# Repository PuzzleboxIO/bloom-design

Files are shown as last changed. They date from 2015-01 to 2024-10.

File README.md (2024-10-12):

bloom-design
============

Puzzlebox Bloom - 3D Design

by Puzzlebox Productions, LLC
http://puzzlebox.io/bloom

puzzlebox_bloom_openscad

Watch the video (https://www.youtube.com/watch?v=KhwO3Cl5jvA)

Assembly Guide:
https://puzzlebox.io/bloom-assembly/

License: Creative Commons - Attribution - Share Alike
https://creativecommons.org/licenses/by-sa/3.0

source credit: "Blossoming Lamp" by Emmett Lalish [https://www.thingiverse.com/thing:37926]
source credit: "Arduino OpenSCAD mounting library (v2.0)" by Kelly Egan [https://github.com/kellyegan/OpenSCAD-Arduino-Mounting-Library]
source credit: "Pin Connectors V3" by Tony Buser and Emmett Lalish [http://www.thingiverse.com/thing:33790]
source credit: "Write.scad" by Harlan Martin [http://www.thingiverse.com/thing:16193]

creative credit: Patrick Jouin [http://www.mgxbymaterialise.com/limited-editions/mgxmodel/detail/detail/71]

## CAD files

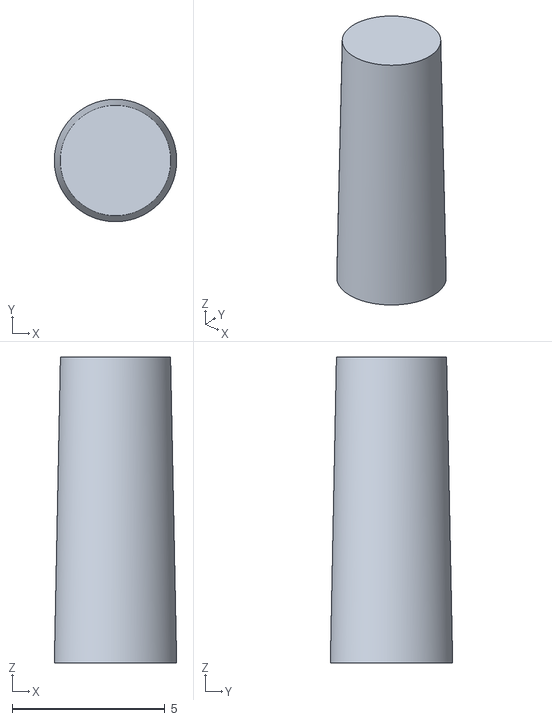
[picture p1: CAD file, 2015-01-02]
render/Peg.stl
4.00 x 4.00 x 10.0

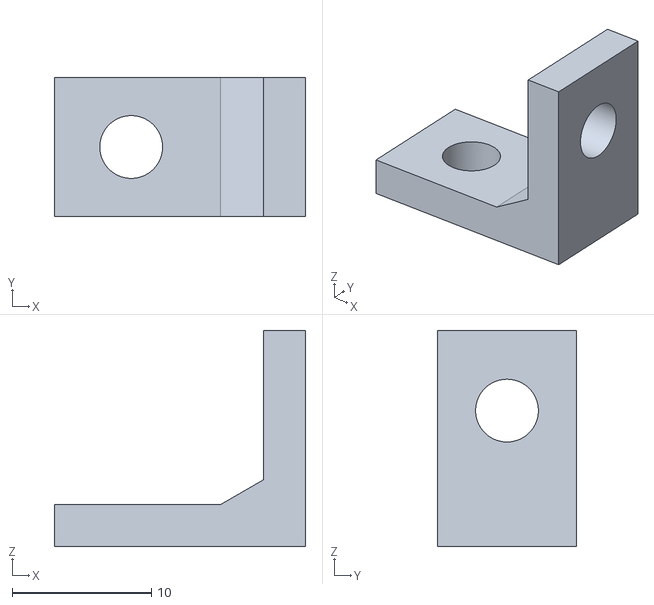
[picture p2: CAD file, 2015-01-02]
render/Clip.stl
18.0 x 10.0 x 15.5

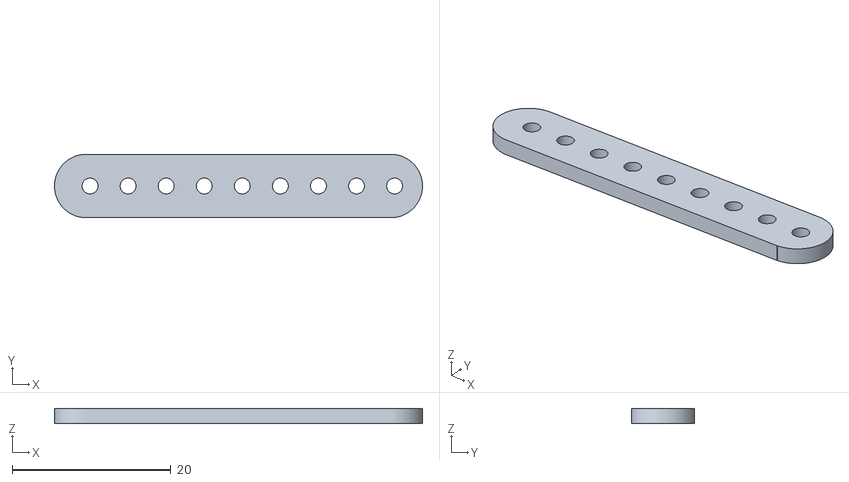
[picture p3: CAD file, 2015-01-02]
render/Rod.stl
46.4 x 8.00 x 1.92

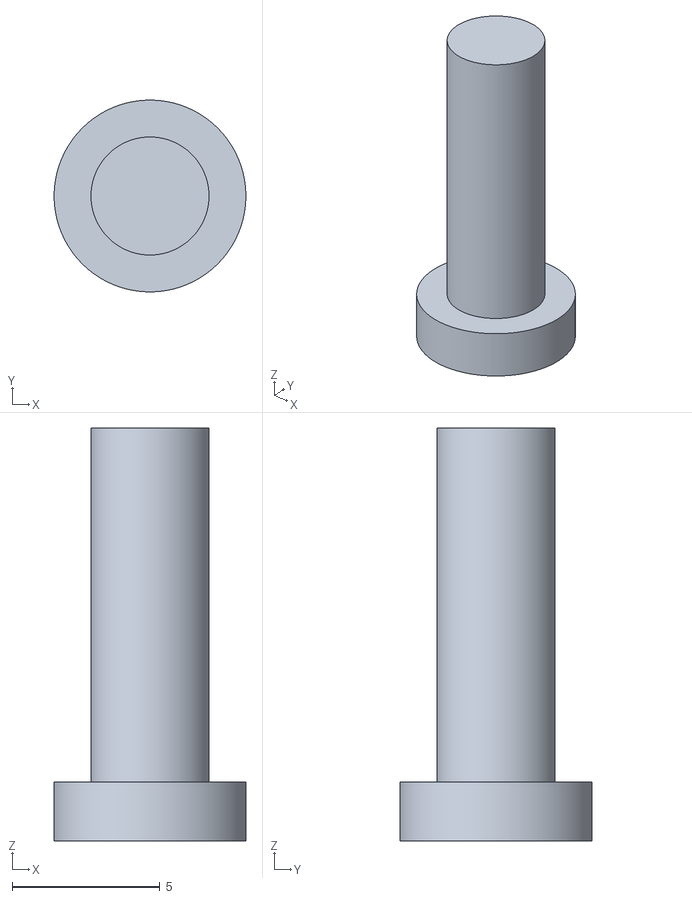
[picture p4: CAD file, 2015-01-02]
render/Cover.stl
6.50 x 6.50 x 14.0

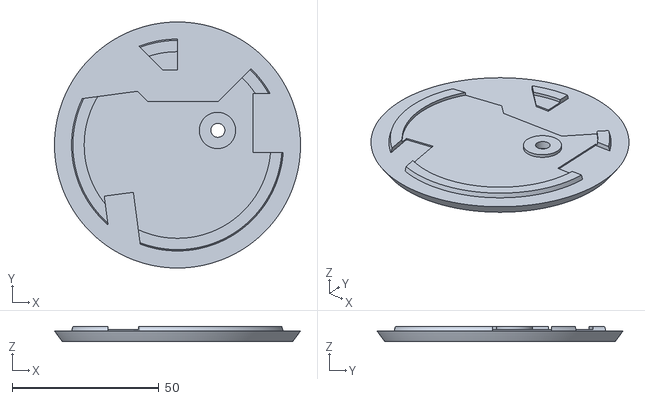
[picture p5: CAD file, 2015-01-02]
render/Bottom.stl
83.8 x 83.8 x 5.09

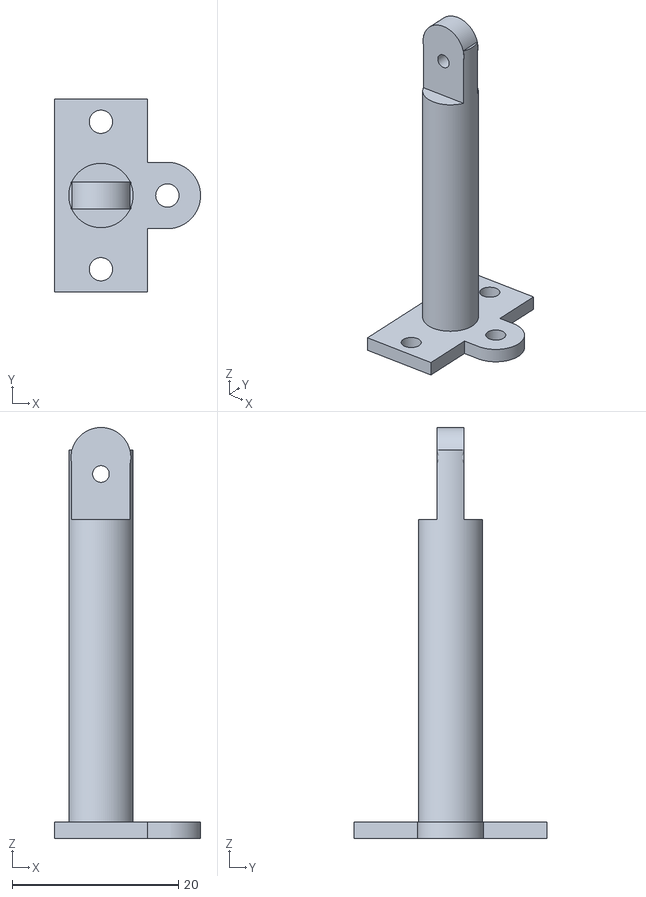
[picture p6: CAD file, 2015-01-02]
render/Piston.stl
17.6 x 23.2 x 49.5

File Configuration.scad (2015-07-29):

// Puzzlebox Bloom
//
// component: Configuration
//
// by Puzzlebox Productions, LLC
// http://puzzlebox.io/bloom
//
// License: Creative Commons - Attribution - Share Alike
//          https://creativecommons.org/licenses/by-sa/3.0
//
// source credit: "Blossoming Lamp" by Emmett Lalish [https://www.thingiverse.com/thing:37926]
// creative credit: Patrick Jouin [http://www.mgxbymaterialise.com/limited-editions/mgxmodel/detail/detail/71]
//
// source credit: "Arduino OpenSCAD mounting library (v2.0)" by Kelly Egan [https://github.com/kellyegan/OpenSCAD-Arduino-Mounting-Library]
// source credit: "Pin Connectors V3" by Tony Buser and Emmett Lalish [http://www.thingiverse.com/thing:33790]
// source credit: "Write.scad" by Harlan Martin [http://www.thingiverse.com/thing:16193]


// Design
// Note: All measurements are in mm


print_scale = 0.8; // divide by this number pricely-measured 
                   // facets which cannot be scaled down
                   // for example, screw holes, LEDs, docks, etc.


// Tolerances
tol=0.45 / print_scale; // tolerance for sliding [Printrbot Simple Metal (2014, 2015)]
// tol=0.4 / print_scale; // tolerance for sliding [MakerBot Replicator 2]
// tol=0.3 / print_scale; // tolerance for sliding [Ultimaker 2]
// tol=0.4 / print_scale; // tolerance for sliding [daVinci 1.0]


// Bulb Platform
bulb_platform_position = -51; // flush with top of socket (w/ heigth 6)
bulb_platform_diameter = 34;
bulb_platform_height = 4; // (thickness)
// bulb_platform_height = 7; // (thickness)


// Bulb Pivot
// pivot_outer_diameter = 12.5 + 0.5;
pivot_outer_diameter = 12.5 + 0.5 + 1;
pivot_inner_diameter = 4;

// pivot_thickness = 4 + 0.5;
// pivot_thickness = 4 + 0.5 + 1;
pivot_thickness = 4 + 0.5 + 2;

// pivot_reinforcements_thickness = pivot_thickness-1;
pivot_reinforcements_thickness = 3.5;

pivot_extension = 2.5 + 2 + 5;
// pivot_position_z = bulb_platform_position - bulb_platform_height /2 - pivot_extension - 1.825; // dropped by 2.5mm in order to compensate for the head of the pivot arm
// pivot_position_z = bulb_platform_position - bulb_platform_height /2 - pivot_extension - 2.825 + 0.132;
pivot_position_z = bulb_platform_position - bulb_platform_height /2 - pivot_extension - 2.825 + 0.132 + 0.25;
// pivot_hole_position_z = pivot_position_z-pivot_extension/2 + 2.5 + 2;
pivot_hole_position_z = pivot_position_z-pivot_extension/2 + 2.5;
reinforcement_height = 13;
pivot_round_screw_hole = false;
pivot_square_bolt_hole = true;
// pivot_bolt_screw_hole_diameter = pivot_thickness-1;
pivot_bolt_screw_hole_diameter = 3.5;
// bulb_pivot_offset_x_purple = 10;
bulb_pivot_offset_x_purple = 10+1+0.1;
// bulb_pivot_offset_x_violet = -10;
bulb_pivot_offset_x_violet = -10-1-0.1;


// Branch
slice_mount_plate = false; // Crop a vertical stripe out of the mount plate


// Blossom
height_of_lamp = 76.1;
lamp_error_at_z = height_of_lamp - 31;
height_of_lamp_crop = height_of_lamp - lamp_error_at_z + 10; // crop before z error in model
lamp_crop_pos_z = lamp_error_at_z + (height_of_lamp_crop/2); // "

height_of_lamp_crop = height_of_lamp + 119.75; // crop entire bulb
lamp_crop_pos_z = 50; // "


// Petals
petal_stand_height = 3;


// Cage screw holes
cage_screw_diameter = 4 / print_scale;
// cage_screw_height = 15;
// cage_screw_height = 15 + 100;
// cage_screw_height = 15 + 35; // should be enough to reach through to outer edge of stand but not intersect with support ring in base socket
cage_screw_height = 15 -1 ; // leave a 1-2mm wall between edge of cage()

cage_screw_tilt_degrees = 12;


// Light holes
light_hole_diameter = 24; // easy_mount_cropping
// light_hole_diameter = 15; // small diameter
// light_hole_diameter = 12.5 / print_scale; // if you try to scale this it will create a gap between the purple pivots underneath

// led_diameter = 6 / print_scale; // exact measure is closer to 5.5mm but the heat seems to shring the final size of the hole
led_diameter = (light_hole_diameter * print_scale) / print_scale; // grow large to let more light through


// Bulb Socket
// bulb_socket_crop_position_height = 47; // top of male arm joints
bulb_socket_crop_position_height = 38;
bulb_socket_split_x = 100;
bulb_socket_split_y = 100;
bulb_socket_split_z = 172;
bulb_socket_alternate_joints_position = false; // original lamp alternates

bulb_socket_height = 20; // (calculated)

socket_outer_diameter = 75.75; // (calculated)
socket_rim = socket_outer_diameter - 15.2; // (calculated)


// Base Stand
stand_crop_microusb_slot = true;
stand_crop_dc_adapter_slot = true;

stand_render_microcontroller_mount = true;

stand_crop_microcontroller_mount = true;
// stand_crop_microcontroller_mount = false;

stand_render_lid_mount = true;

build_base_socket = true;
// build_base_socket = false;

// build_inner_support_walls = true;
build_inner_support_walls = false;

// linear_tapered_cylinder = true;
linear_tapered_cylinder = false; // original base socket

// slice_socket_center_from_bottom = true;
slice_socket_center_from_bottom = false;

// enable_render_side_petals = true;
// enable_render_side_petals = false;
enable_render_side_petals_left = false;
enable_render_side_petals_right = false;
// enable_render_side_petals_right = true;

// enable_front_wall_hole = true;
enable_front_wall_hole = false;

// front_wall_hole_tapered = false;
front_wall_hole_tapered = true;

// reinforce_front_wall_hole = true;
reinforce_front_wall_hole = false;

stand_extrude_walls = true;

stand_crop_position_x = 87.5;
stand_crop_position_height = 70;
stand_crop_x = 100;
stand_crop_y = 100;
stand_crop_z = 172;

// rotate_screw_holes = [0,0,0]; // 2 holes on forward half, to either side
rotate_screw_holes = [0,0,180]; // 1 hole on forward half, centered
rotate_socket_screw_holes_offset = [0,0,0];

// slice_socket_up_from_bottom = 22.5;
slice_socket_up_from_bottom = 22.5-10;

stand_test_brim_diameter = 135.925;
stand_test_brim_height = 5;

// stand_height = 42.5; // (calculated)
stand_height = 43; // (calculated)
base_extrude_walls_scale_height = 44;

// stand_total_height = stand_height+bulb_socket_height;
stand_total_height = stand_height+bulb_socket_height*2;

stand_cylinder_diameter = 97.5; // (calculated)
stand_cylinder_width = 8.75; // (calculated)
// stand_cylinder_width = 8.5175; // "
// stand_cylinder_width = 8.515; // "
// stand_cylinder_width = 8.5; // "

// base_cylinder_side_hole = 50;
base_cylinder_side_hole = 60;

stand_extrude_walls_scale = (stand_cylinder_diameter - stand_cylinder_width) / stand_cylinder_diameter;

stand_petal_crop_scale_large = 1.2;
stand_petal_crop_scale_medium = 0.8;
stand_petal_crop_scale_small = 0.6;
stand_petal_crop_scale_rear = 1;
// stand_petal_crop_scale_rear = 0.95;
// stand_petal_crop_scale_rear_petal = 0.6;
stand_petal_crop_scale_rear_petal = 0.6;

base_servo_mount_offset_x = -5-5-5;
// base_servo_mount_offset_y = 7.5;
// base_servo_mount_offset_y = -8;
// base_servo_mount_offset_y = 7.5-8;
// base_servo_mount_offset_y = 1.5;
base_servo_mount_offset_y = 1.5-2.5; // controls how far back the servo sits under the piston and connecting rod
base_servo_mount_offset_z = 31.5*2;

// base_servo_mount_crop_from_back = 3.5; // widened for TowerPro MG995
base_servo_mount_crop_from_back = 2.5;

// base_servo_mount_screws_offset_z = -0.75;
base_servo_mount_screws_offset_z = -1;

stand_socket_height = 25; // (calculated)
// stand_socket_crop_top = 3;
stand_socket_crop_top = 4; // (measured)

// actual_stand_height = stand_height+bulb_socket_height+mount_plate_thickness/4+16.7;
// actual_stand_height = 81.325;
actual_stand_height = 83;
stand_extension = 22;
adjusted_stand_height = actual_stand_height + stand_extension;

servo_cylinder_height = 53;

stand_wall_width = 3.5;

servo_cube_x=50;
servo_cube_y=80;
servo_cube_z=servo_cylinder_height;

extrude_base_scale_x = 0.95;
extrude_base_scale_y = 0.95;
extrude_base_scale_z = 0.86359;
extrude_base_t = -5;

stand_servo_x_offset = 0;
stand_servo_y_offset = -34+10;
stand_servo_z_offset = 30;

// microcontroller_height = 15 / print_scale;
// microcontroller_length = 76 / print_scale;
// microcontroller_width = 54 / print_scale;

// microcontroller_height = 15;
microcontroller_height = 13;
microcontroller_length = 76;
// microcontroller_width = 54;
microcontroller_width = 58;

// microcontroller_x_offset = 18;
microcontroller_x_offset = 18-7;
microcontroller_y_offset = 12;
microcontroller_offset_from_bottom = 12;

// microcontroller_bolt_width = 0;
microcontroller_bolt_width = 2.5;
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

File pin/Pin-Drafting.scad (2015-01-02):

// Puzzlebox Bloom
//
// component: Pin
//
// edition: Drafting
//
// by Puzzlebox Productions, LLC
// http://puzzlebox.io/bloom
//
// License: Creative Commons - Attribution - Share Alike
//          https://creativecommons.org/licenses/by-sa/3.0


// Libraries
use <../library/Pin_Connectors_V3/pins.scad>
include <../library/OpenSCAD-Arduino-Mounting-Library/arduino.scad>
include <../Configuration.scad>
include <../mount/Mount.scad>
include <../pin/Pin.scad>


// Rendering quality (calculated via angle in degrees)
$fa=12;
$fn=30;

// Main
assemble_pin();

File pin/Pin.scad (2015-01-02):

// Puzzlebox Bloom
//
// component: Pin (Replacement Screw and Mounting Pin)
//
// designed by Puzzlebox Productions, LLC
// http://puzzlebox.io/bloom
//
// Copyright Puzzlebox Productions, LLC (2014-2015)
//
// License: Creative Commons - Attribution - Share Alike
//          https://creativecommons.org/licenses/by-sa/3.0
//
// source credit: "Pin Connectors V3" by Tony Buser and Emmett Lalish [http://www.thingiverse.com/thing:33790]


// Libraries
use <../library/Pin_Connectors_V3/pins.scad>


module assemble_pin(){
	
	assemble_mounting_pin();
	
}


module assemble_mounting_pin(){
	
	// 	pin(h=pcbHeight+mount_height,r=mountingHoleRadius/2,lh=lip_height,lt=lip_thickness,t=pin_tolerance);
	// 	pin(h=length,r=diameter/2,lh=lip_height,lt=lip_thickness,t=pin_tolerance);
	// 	pinpeg(h=length+pcbHeight+mount_height,r=diameter/2,lh=lip_height,lt=lip_thickness,t=pin_tolerance);
	// 	pinpeg(h=pcbHeight+mount_height,r=mountingHoleRadius,lh=lip_height,lt=lip_thickness,t=pin_tolerance);
	
	
	
	echo ("pcbHeight", pcbHeight);
	echo ("mount_height", mount_height);
	echo ("mountingHoleRadius", mountingHoleRadius);
	
	
	
	// V2
	// 	pinpeg(h=pcbHeight+mount_height,r=mountingHoleRadius);
	
	// 	translate([10,0,0])
	// 	pinpeg(h=5+pcbHeight+mount_height,r=mountingHoleRadius);
	
	// 	translate([20,0,0])
	// 	pinpeg(h=length,r=mountingHoleRadius);
	
	// 	translate([0,0,0])
	// 	pinpeg(h=pcbHeight *2 + 3 + mount_height, r = mountingHoleRadius, lh=3, lt=1, bh=1, br=mountingHoleRadius + 1);
	// 
	// 	
	// 	translate([-10,0,0])
	// 	pinpeg(h=pcbHeight*2 + 3 + mount_height + 1, r = mountingHoleRadius, lh=3, lt=1, bh=1, br=mountingHoleRadius + 1);
	// 
	// 	translate([-20,0,0])
	// 	pinpeg(h=pcbHeight*2 + 3 + mount_height + 2, r = mountingHoleRadius, lh=3, lt=1, bh=1, br=mountingHoleRadius + 1);
	// 
	// 	translate([-30,0,0])
	// 	pinpeg(h=pcbHeight*2 + 3 + mount_height + 4, r = mountingHoleRadius, lh=3, lt=1, bh=1, br=mountingHoleRadius + 1);
	
	
	
	
	
	// Defaults V3 demo
	translate([-20,0,0])
	pin_connectors_v3_examples();
	
	translate([80,-30,0]){
		// Test standoff
		translate([-100,0,0])
		mount_plate_standoff();
		
		// Test mount plate
		translate([-120,0,0])
		mount_plate_standoff_test();
	}
	
	
	// V3
	length = pcbHeight*2 + mount_height;
	
	
	build_pin(length=length, radius=mountingHoleRadius);
	
	translate([10,0,0])
	build_pin(length=length+3, radius=mountingHoleRadius);
	
	translate([20,0,0])
	build_pin(length=length+3*2, radius=mountingHoleRadius);
	
	translate([30,0,0])
	build_pin(length=length+3*3, radius=mountingHoleRadius);
	
	translate([40,0,0])
	build_pin(length=length+3*4, radius=mountingHoleRadius);
	
	translate([50,0,0])
	build_pin(length=length+3*5, radius=mountingHoleRadius);
	
	
	
	
	translate([0,-30,0]){
		
		translate([50,0,0])
		build_pin(length=length, radius=mountingHoleRadius);
		
		translate([40,0,0])
		build_pin(length=length+3, radius=mountingHoleRadius);
		
		translate([30,0,0])
		build_pin(length=length+3*2, radius=mountingHoleRadius);
		
		translate([20,0,0])
		build_pin(length=length+3*3, radius=mountingHoleRadius);
		
		translate([10,0,0])
		build_pin(length=length+3*4, radius=mountingHoleRadius);
		
		translate([0,0,0])
		build_pin(length=length+3*5, radius=mountingHoleRadius);
	}
	
	
	
	
	
	// 	translate([0,length/2,0])
	// 	pin(h=4,r=mountingHoleRadius,lh=lip_height,lt=lip_thickness,t=pin_tolerance, side=true);
	
	// 	pinshaft(h=length,r=mountingHoleRadius,t=pin_tolerance, side=true);
	
	// 	rotate([0,0,180])
	// 	translate([0,length/2,0])
	// 	pin(h=4,r=mountingHoleRadius,lh=lip_height,lt=lip_thickness,t=pin_tolerance, side=true);
	
}

// module pinpeg(h=20, r=4, lh=3, lt=1) {
//   union() {
//     translate([0, -h/4+0.05, 0]) pin(h/2+0.1, r, lh, lt, side=true);
//     translate([0, h/4-0.05, 0]) rotate([0, 0, 180]) pin(h/2+0.1, r, lh, lt, side=true);
//   }
// }


module pin_connectors_v3_examples(){
	
	// 	object=0;//[0:pin,1:pinpeg,2:pinhole]
	length=20;
	diameter=8;
	//Only affects pinhole
	hole_twist=0;//[0:free,1:fixed]
	//Only affects pinhole
	hole_friction=0;//[0:loose,1:tight]
	//Radial gap to help pins fit into tight holes
	pin_tolerance=0.2;
	//Extra gap to make loose hole
	loose=0.3;
	lip_height=3;
	lip_thickness=1;
	hf=hole_friction==0 ? false : true;
	ht=hole_twist==0 ? false : true;
	
	pin(h=length,r=diameter/2,lh=lip_height,lt=lip_thickness,t=pin_tolerance);
	
	translate([-20,0,0])
	pinpeg(h=length,r=diameter/2,lh=lip_height,lt=lip_thickness,t=pin_tolerance);
	
	
	translate([-40,0,0])
	pinhole(h=length,r=diameter/2,lh=lip_height,lt=lip_thickness,t=loose,tight=hf,fixed=ht);
	
	translate([-45,-25,0])
	difference(){
		translate([0,0,length/2])
		cube([diameter*2,diameter*2,length],center=true);
		pinhole(h=length,r=diameter/2,lh=lip_height,lt=lip_thickness,t=loose,tight=hf,fixed=ht);
	}
	
	
}


module mount_plate_standoff(){
	
	// 	holePlacement(boardType=LEONARDO)
	pin_standoff(
		boardType=LEONARDO, 
		height=mount_height, 
		holeRadius=mountingHoleRadius,
		mountType=PINHOLE, 
		pinhole_height=pcbHeight+mount_height);
	
	
}


module mount_plate_standoff_test(){
	
	
	difference(){
		
		union() {
			
			// 			boardShape(boardType=LEONARDO, offset=3, height=pcbHeight);
			
			translate([0,0,pcbHeight/2])
			cube([15,20,pcbHeight],center=true);
			
			
			// 			holePlacement(boardType=LEONARDO)
			// 			translate([0,0,pcbHeight])
			pin_standoff(
				boardType=LEONARDO, 
				height=mount_height, 
				holeRadius=mountingHoleRadius,
				mountType=PINHOLE, 
				pinhole_height=pcbHeight+mount_height);
			
		}	
		
		// 		holePlacement(boardType = LEONARDO)
		
		translate([0, 0, -0.01])
		pinhole(h=pcbHeight+mount_height+3.35,
				  r=mountingHoleRadius+0.1, 
			 lh=lip_height, 
			 lt=lip_thickness, 
			 t=loose, 
			 tight=true,
			 fixed=true);
		
	}
	
	
}


module build_pin(length=0, radius=mountingHoleRadius) {
	
	echo ("length", length);
	
	translate([0,length/2,0])
	pin(h=3,r=mountingHoleRadius,lh=lip_height,lt=lip_thickness,t=pin_tolerance, side=true);
	
	pinshaft(h=length,r=mountingHoleRadius,t=pin_tolerance, side=true);
	
	rotate([0,0,180])
	translate([0,length/2,0])
	pin(h=3.75,r=mountingHoleRadius-0.1,lh=lip_height,lt=lip_thickness,t=pin_tolerance, side=true);
	
}

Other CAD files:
pin/Pin-Render.scad
base/Base-Drafting.scad
base/Base-Render.scad
base/Base.scad
bloom/Bloom-Drafting.scad
bloom/Bloom-Render.scad
bloom/Bloom.scad
bottom/Bottom-Drafting.scad
bottom/Bottom-Render.scad
bottom/Bottom.scad
branch/Branch-Drafting.scad
branch/Branch-Render.scad
branch/Branch.scad
bulb/Bulb-Drafting.scad
bulb/Bulb-Render.scad
bulb/Bulb.scad
clip/Clip-Drafting.scad
clip/Clip-Render.scad
clip/Clip.scad
cover/Cover-Drafting.scad
cover/Cover-Render.scad
cover/Cover.scad
lens/Lens-Render.scad
lens/Lens.scad
mount/Mount-Drafting.scad
mount/Mount-Render.scad
mount/Mount.scad
peg/Peg-Drafting.scad
peg/Peg-Render.scad
peg/Peg.scad
petals/Petals-Drafting.scad
petals/Petals-Render.scad
petals/Petals.scad
piston/Piston-Drafting.scad
piston/Piston-Render.scad
piston/Piston.scad
rod/Rod-Drafting.scad
rod/Rod-Render.scad
rod/Rod.scad
servo/Servo.scad
socket/Socket-Drafting.scad
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

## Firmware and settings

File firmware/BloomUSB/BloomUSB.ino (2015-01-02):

/*
 * 
 * Puzzlebox - Bloom
 * 
 * Bloom RGB / Servo Sketch
 * 
 * Copyright Puzzlebox Productions, LLC (2014)
 * 
 * This code is released under the GNU Pulic License (GPL) version 3
 * 
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
 * For more information about this licence please refer to http://www.gnu.org/copyleft/gpl.html
 * 
 * For more details about the product please check http://puzzlebox.io/bloom
 * 
 * Original Author: Steve Castellotti <sc@puzzlebox.io>
 * 
 * Modified 2014-12-30
 * by Steve Castellotti <sc@puzzlebox.io>
 * 
 */

#include <Servo.h>

#define DEBUG_OUTPUT 0 
//#define DEBUG_OUTPUT 1 // 1 for debug

#define SERVO_PIN_BLOOM 7

#define RGB_PIN_RED 3
#define RGB_PIN_GREEN 5
#define RGB_PIN_BLUE 6

// Counter-clockwise Open
#define POSITION_BLOOM_OPEN 31
#define POSITION_BLOOM_CLOSED 150

// Clockwise Open
//#define POSITION_BLOOM_OPEN 150
//#define POSITION_BLOOM_CLOSED 31

#define POSITION_BLOOM_SETUP 70 // Percentage

#define TIME_BLOOM_OPEN 3000 // Open the Bloom for three seconds and then close it
#define TIME_BLOOM_CYCLE 3000
#define TIME_BLOOM_CYCLE_SLOW_STEPS 60 // time for each percentage step
#define TIME_BLOOM_DEMO_CYCLE 2500
#define TIME_BLOOM_RGB_CYCLE 10

// Uncomment the line below if using a Common Anode LED
// such as the "T-1 3/4 5mm Full Color LED" from Radioshack [276-028]:
// https://www.radioshack.com/product/index.jsp?productId=3020765
//#define COMMON_ANODE

Servo servoBloom;

char _command;
char lastCommand = '0'; // closed

char message[] = "Bloom";


unsigned char buf[16] = {0};
unsigned char len = 0;

int index;

int percentage;
int degrees;


// ################################################################

/////////
//SETUP//
/////////

void setup() {
	
	// Start off with the LED off.
	setColourRgb(0,0,0);
	
	
	Serial.begin(115200);
	
	servoBloom.attach(SERVO_PIN_BLOOM);
	
	servoBloom.write(POSITION_BLOOM_CLOSED);
	
	delay(2000);
	
	// White
	setColourRgb(255, 255, 255);
	servoTransition(0,POSITION_BLOOM_SETUP);
	
} // setup


// ################################################################

/////////////
//MAIN LOOP//
/////////////

void loop() {
	
	parseSerialInput();
	
} // Main loop


// ################################################################

void parseSerialInput() {
	
	if (Serial.available() > 0)  {
		
		_command = Serial.read();
		
		#if DEBUG_OUTPUT
		Serial.print("Serial.read(): ");
		Serial.println(_command);
		#endif
		
		parseCommand(_command);
		
		//    if (_command != '0') {
		//      // Don't directly set lastCommand to "closed"
		lastCommand = _command;
		//    }
		
	}
	
} // parseSerialInput()


// ################################################################

int parseValue() {
	
	char inByte=0;
	int a=0;
	int b=0;
	int c=0;
	int newValue=0;
	
	while (Serial.available() == 0);
	inByte = Serial.read() - '0';
	a = inByte;
	
	while (Serial.available() == 0);
	inByte = Serial.read() - '0';
	b = inByte;
	
	while (Serial.available() == 0);
	inByte = Serial.read() - '0';
	c = inByte;
	
	newValue = (a * 100) + (b * 10) + c;
	
	return(newValue);
	
} // parseValue


// ################################################################


void setDegrees() {
  
	#if DEBUG_OUTPUT
	Serial.println("setDegrees()");
	#endif
	
	int degrees = parseValue();
	
	servoBloom.write(degrees);

  
}


// ################################################################

void setRGB() {
  
	#if DEBUG_OUTPUT
	Serial.println("setRGB()");
	#endif
  
	unsigned int rgbColour[3];
	
	rgbColour[0] = parseValue();
	rgbColour[1] = parseValue();
	rgbColour[2] = parseValue();  
	
	setColourRgb(rgbColour[0], rgbColour[1], rgbColour[2]);
	
}


// ################################################################

void setColourRgb(unsigned int red, unsigned int green, unsigned int blue) {
	
	// 	#if DEBUG_OUTPUT
	// 	Serial.println("setColourRgb([" + String(red) + ", " + String(green) + ", " + String(blue) + "])");
	// 	#endif
	
	#ifdef COMMON_ANODE
	red = 255 - red;
	green = 255 - green;
	blue = 255 - blue;
	#endif
	
	analogWrite(RGB_PIN_RED, red);
	analogWrite(RGB_PIN_GREEN, green);
	analogWrite(RGB_PIN_BLUE, blue);
	
}



// ################################################################

void loopRGB() {
	unsigned int rgbColour[3];
	
	// Start off with red.
	rgbColour[0] = 255;
	rgbColour[1] = 0;
	rgbColour[2] = 0;  
	
	while (1) {
	
		// Choose the colours to increment and decrement.
		for (int decColour = 0; decColour < 3; decColour += 1) {
			int incColour = decColour == 2 ? 0 : decColour + 1;
			
			// cross-fade the two colours.
			for(int i = 0; i < 255; i += 1) {
				rgbColour[decColour] -= 1;
				rgbColour[incColour] += 1;
				
				setColourRgb(rgbColour[0], rgbColour[1], rgbColour[2]);
				delay(TIME_BLOOM_RGB_CYCLE);
			}
		}
		
		// Quit loop if a new control command has been issued
		if (Serial.available() > 0) {  
			break;
		}
	}
}


// ################################################################

void loopRGBServo() {
	
// 	int percentage = 0;
	percentage = 0;
	
	boolean direction_open = true;
	
	servoBloom.write(POSITION_BLOOM_CLOSED);
	
	int countRGB = 0;
	
	unsigned int rgbColour[3];
	
	// Start off with red.
	rgbColour[0] = 255;
	rgbColour[1] = 0;
	rgbColour[2] = 0;  
	
	
	while (1) {
		
		
		// Choose the colours to increment and decrement.
		for (int decColour = 0; decColour < 3; decColour += 1) {
			int incColour = decColour == 2 ? 0 : decColour + 1;
			
			// cross-fade the two colours.
			for(int i = 0; i < 255; i += 1) {
				rgbColour[decColour] -= 1;
				rgbColour[incColour] += 1;
				
				setColourRgb(rgbColour[0], rgbColour[1], rgbColour[2]);
				delay(TIME_BLOOM_RGB_CYCLE);
				
				countRGB = countRGB + TIME_BLOOM_RGB_CYCLE;
				if (countRGB >= TIME_BLOOM_CYCLE_SLOW_STEPS){
					
					countRGB = 0;
					
					if (direction_open) {
						percentage++;
						servoSetPercentage(percentage);
						if (percentage == 100)
							direction_open = false;
					} else {
						percentage--;
						servoSetPercentage(percentage);
						if (percentage == 0)
							direction_open = true;
					}
				}
			}
		}
		
		// Quit loop if a new control command has been issued
		if (Serial.available() > 0) {  
			break;
		}
		
	}
	
}


// ################################################################

void servoSetPercentage(int new_percent) {
	
// 	#if DEBUG_OUTPUT
// 		Serial.println("servoSetPercentage()");
// 	#endif
	
	//  int percent = parseValue();
	
// 	#if DEBUG_OUTPUT
// 		Serial.print("--> Percentage: ");
// 		Serial.println(percent);
// 	#endif
	
// 	int degrees = POSITION_BLOOM_CLOSED;
	degrees = POSITION_BLOOM_CLOSED;
	
	// convert percentage to servo degrees
	if (POSITION_BLOOM_CLOSED >= POSITION_BLOOM_OPEN) {
		degrees = POSITION_BLOOM_CLOSED - (new_percent * (POSITION_BLOOM_CLOSED - POSITION_BLOOM_OPEN) / 100);
	} else {
		degrees = (new_percent * (POSITION_BLOOM_OPEN - POSITION_BLOOM_CLOSED) / 100) + POSITION_BLOOM_CLOSED;
	}
	
// 	#if DEBUG_OUTPUT
// 		Serial.print("--> Position: ");
// 		Serial.println(degrees);
// 	#endif
	
	servoBloom.write(degrees);
	
}


// ################################################################

void bloomClose() {
	
	#if DEBUG_OUTPUT
	Serial.println("bloomClose()");
	#endif
	
	servoBloom.write(POSITION_BLOOM_CLOSED);
	
}


// ################################################################

void bloomOpen() {
	
	#if DEBUG_OUTPUT
	Serial.println("bloomOpen()");
	#endif
	
	servoBloom.write(POSITION_BLOOM_OPEN);
	
}


// ################################################################

void bloomOpenAndClose() {
	
	#if DEBUG_OUTPUT
	Serial.println("bloomOpenAndClose()");
	#endif
	
	servoBloom.write(POSITION_BLOOM_OPEN);
	
	delay(TIME_BLOOM_OPEN);
	
	servoBloom.write(POSITION_BLOOM_CLOSED);
	
}


// ################################################################

void bloomCycle() {
	
	#if DEBUG_OUTPUT
	Serial.println("bloomCycle()");
	#endif
	
	while (1) {
		
		servoBloom.write(POSITION_BLOOM_OPEN);
		
		delay(TIME_BLOOM_CYCLE);
		
		servoBloom.write(POSITION_BLOOM_CLOSED);
		
		delay(TIME_BLOOM_CYCLE);
		
		if (Serial.available() > 0) {
			
			break;
			
		}
		
	}
	
}


// ################################################################

void bloomCycleSlow() {
	
	#if DEBUG_OUTPUT
	Serial.println("bloomCycleSlow()");
	#endif
	
// 	int degrees = POSITION_BLOOM_CLOSED;
	degrees = POSITION_BLOOM_CLOSED;
// 	int percentage = 0;
	percentage = 0;
	
	while (1) {
		
		
		servoTransition(0, 100);
		
		
		#if DEBUG_OUTPUT
		Serial.println("--> Position: Opened");
		#endif
		
		delay(TIME_BLOOM_CYCLE);
		
		
		servoTransition(100, 0);
		
		
		#if DEBUG_OUTPUT
		Serial.println("--> Position: Closed");
		#endif
		
		
		delay(TIME_BLOOM_CYCLE);
		
		
		// Quit loop if a new control command has been issued
		if (Serial.available() > 0) {  
			break;
		}
		
	}
	
}


// ################################################################

void servoTransition(int start_percentage, int end_percentage) {
	
	
// 	int degrees = POSITION_BLOOM_CLOSED;
	degrees = POSITION_BLOOM_CLOSED;
// 	int percentage = 0;
	percentage = 0;
	
	
	if (start_percentage < end_percentage) {
		
		for (percentage=start_percentage;percentage<=end_percentage;percentage++) {
			
			// convert percentage to servo degrees
			if (POSITION_BLOOM_CLOSED >= POSITION_BLOOM_OPEN) {
				degrees = POSITION_BLOOM_CLOSED - (percentage * (POSITION_BLOOM_CLOSED - POSITION_BLOOM_OPEN) / 100);
			} else {
				degrees = (percentage * (POSITION_BLOOM_OPEN - POSITION_BLOOM_CLOSED) / 100) + POSITION_BLOOM_CLOSED;
			}
			
			servoBloom.write(degrees);
			delay(TIME_BLOOM_CYCLE_SLOW_STEPS);
			
		}
	}
	
	
	else if (start_percentage > end_percentage) {
		
		
		for (percentage=start_percentage;percentage>=end_percentage;percentage--) {
			
			// convert percentage to servo degrees
			if (POSITION_BLOOM_CLOSED >= POSITION_BLOOM_OPEN) {
				degrees = POSITION_BLOOM_CLOSED - (percentage * (POSITION_BLOOM_CLOSED - POSITION_BLOOM_OPEN) / 100);
			} else {
				degrees = (percentage * (POSITION_BLOOM_OPEN - POSITION_BLOOM_CLOSED) / 100) + POSITION_BLOOM_CLOSED;
			}
			
			servoBloom.write(degrees);
			delay(TIME_BLOOM_CYCLE_SLOW_STEPS);
			
		}
	
	}
	
}


// ################################################################

void rgbTransitionManual() {
	
	#if DEBUG_OUTPUT
	Serial.println("rgbTransitionManual()");
	#endif
	
	unsigned int rgbStart[3];
	
	rgbStart[0] = parseValue();
	rgbStart[1] = parseValue();
	rgbStart[2] = parseValue();
	
	
	unsigned int rgbEnd[3];
	
	rgbEnd[0] = parseValue();
	rgbEnd[1] = parseValue();
	rgbEnd[2] = parseValue();  
	
	
	rgbTransition(rgbStart[0], rgbStart[1], rgbStart[2], 
					  rgbEnd[0], rgbEnd[1], rgbEnd[2]);
	
}


// ################################################################

void rgbTransition(unsigned int start_red, unsigned int start_green, unsigned int start_blue,
						 unsigned int end_red, unsigned int end_green, unsigned int end_blue) {
	
	unsigned int rgbColour[3];
	
	#if DEBUG_OUTPUT
	Serial.println("rgbTransition()");
	Serial.println(String(start_red) + ", " + String(start_green) + ", " + String(start_blue));
	Serial.println(String(end_red) + ", " + String(end_green) + ", " + String(end_blue));
	#endif
	
	// Begin with entered start values
	rgbColour[0] = start_red;
	rgbColour[1] = start_green;
	rgbColour[2] = start_blue;
	
	setColourRgb(rgbColour[0], rgbColour[1], rgbColour[2]);
	
	
	// Find largest different between start and end colors
	int steps_red = start_red - end_red;
	int steps_green = start_green - end_green;
	int steps_blue = start_blue - end_blue;
	
	int red_step = 1;
	int green_step = 1;
	int blue_step = 1;
	
	
	// 	Serial.println("red_step: " + String(red_step) + ", steps_red: " + String(steps_red));         
	// 	Serial.println("green_step: " + String(green_step) + ", steps_green: " + String(steps_green));         
	// 	Serial.println("blue_step: " + String(blue_step) + ", steps_blue: " + String(steps_blue));   
	
	if (steps_red < 0)
		steps_red = end_red - start_red;
	if (steps_green < 0)
		steps_green = end_green - start_green;
	if (steps_blue < 0)
		steps_blue = end_blue - start_blue;
	
	
	int total_steps = steps_red;
	if (total_steps < steps_green)
		total_steps = steps_green;
	else if (total_steps < steps_blue)
		total_steps = steps_blue;
	
	
	// 	Serial.println("red_step: " + String(red_step) + ", steps_red: " + String(steps_red));         
	// 	Serial.println("green_step: " + String(green_step) + ", steps_green: " + String(steps_green));         
	// 	Serial.println("blue_step: " + String(blue_step) + ", steps_blue: " + String(steps_blue));
	// 	Serial.println("total_steps: " + String(total_steps));        
	
	// cross-fade the two colours.
	for(int i = 0; i < total_steps; i += 1) {
		
		if (rgbColour[0] == 255)
			red_step = -1;
		else if ((rgbColour[0] ==  0) || (rgbColour[0] >  255))
			red_step = 1;
		
		if (rgbColour[1] == 255)
			green_step = -1;
		else if ((rgbColour[1] ==  0) || (rgbColour[1] >  255))
			green_step = 1;                        
		
		if (rgbColour[2] == 255)
			blue_step = -1; 
		else if ((rgbColour[2] ==  0) || (rgbColour[2] >  255))
			blue_step = 1;   
		
		if (steps_red > 0) {
			rgbColour[0] = rgbColour[0] + red_step;
			steps_red = steps_red - 1;
		}
		if (steps_green > 0) {
			rgbColour[1] = rgbColour[1] + green_step;
			steps_green = steps_green - 1;
		}
		if (steps_blue > 0) {
			rgbColour[2] = rgbColour[2] + blue_step;
			steps_blue = steps_blue - 1;
		}
		
		
		setColourRgb(rgbColour[0], rgbColour[1], rgbColour[2]);
		
		delay(TIME_BLOOM_RGB_CYCLE);
	}
	
}


// ################################################################

void parseCommand(char command) {
	
// 	int percentage = 0;
	percentage = 0;
	
	switch (command) {
		
		case '0':  bloomClose(); break;
		case '1':  bloomOpen(); break;
		case '2':  bloomOpenAndClose(); break;
		case '3':  bloomCycle(); break;
		case '4':  bloomCycleSlow(); break;
		case '5':  loopRGBServo(); break;
		case '6':  loopRGB(); break;
		
		case 'Q':  setDegrees(); break;
		case 'R':  setRGB(); break;
		case 'S':  percentage = parseValue(); servoSetPercentage(percentage); break;
		case 'T':  rgbTransitionManual(); break;
		
	}
}


// ################################################################
// ################################################################

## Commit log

2015-01-02 - Initial public release
    [Base-Drafting.scad, Base-Render.scad, Base.scad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]
2015-01-02 - Version 1.0 renders
    [Bottom.stl, Clip.stl, Cover.stl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]
2015-01-02 - widened and shortened slightly
    [Peg.scad]
2015-01-02 - Peg widened and shortened slightly
    [Configuration.scad]
2015-01-02 - shortened and widened
    [Peg.stl]
2015-01-03 - name correction for source credit to "Blossoming Lamp"
    [Base.scad, Bloom.scad, Configuration.scad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]
2015-01-03 - URL added to assembly guide
2015-01-03 - Cover changed back to rounded screw cap
    [Cover.scad]
2015-02-15 - Cura profile for Bloom on Printrbot Simple Metal
2015-03-08 - Tolerance set to 0.45 for Printrbot Simple Metal - STL and Cura profile updated
    [Configuration.scad]
2015-04-09 - Bulb modified for printing on Printrbot Simple Metal (2014, 2015) - Renamed Bulb STL for Ultimaker 2 - printing stand added for printers without a glass platform
    [Bulb.scad, Configuration.scad]
2015-04-27 - microcontoller mounting hole diameter reduces to match custom pins
    [Configuration.scad, Mount.scad, Stand.scad]
2015-07-04 - stand_crop_microusb_slot configuration added - stand_crop_dc_adapter_slot configuration added
    [Configuration.scad, Stand.scad]
2015-07-06 - stand_crop_microcontroller_mount configuration option added
    [Configuration.scad, Stand.scad]
2015-07-06 - stand_render_lid_mount added to configuration
    [Configuration.scad, Stand.scad]
2015-07-07 - bottom_plate_clip_screw_offset configuration added
    [Bottom.scad, Clip.scad, Configuration.scad]
2015-07-07 - debug echo statements commented out
    [Bottom.scad]
2015-07-11 - configuration changes added to support new bottom layout
    [Configuration.scad]
2015-07-11 - option for second mounting screw added to bottom
    [Bottom.scad, Configuration.scad, Stand.scad]
2015-07-12 - bottom_render_upper_inside configuration added
    [Bottom.scad, Configuration.scad]
2015-07-12 - added front right and left screw holes to bottom
    [Bottom.scad, Configuration.scad]
2015-07-14 - bottom_plate_screw_height configuration added
    [Configuration.scad]
2015-07-17 - space between servo mount reinforcement and front right wall removed
    [Stand.scad]
2015-07-22 - increased clip height for upper_clip_screw_crop (the actual screw diameter)
    [Bottom.scad, Configuration.scad]
2015-07-22 - indentation cleanup
    [Stand.scad]
2015-07-23 - bottom_plate_crop_screw_mounts added to configuration
    [Bottom.scad, Configuration.scad]
2015-07-25 - updated diameter for mount_screw_reinforcement() and bottom_clip_screw_crop()
    [Configuration.scad]
2015-07-29 - rotate_socket_screw_holes_offset configuration added
    [Configuration.scad]
